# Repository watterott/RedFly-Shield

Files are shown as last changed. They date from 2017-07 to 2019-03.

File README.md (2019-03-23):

# RedFly-Shield
The RedFly-Shield is a plug-on module with WiFi/WLAN for Arduino.

Alternative: [BlueFly-Shield](https://github.com/watterott/BlueFly-Shield) with Atmel/Microchip ATWINC1500-MR210PB WiFi module.

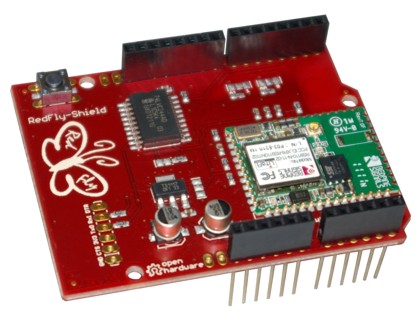
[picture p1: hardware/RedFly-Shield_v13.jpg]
RedFly-Shield


* [Redpine Signals RS9110-N-11-22](http://www.redpinesignals.com/Modules/Internet_of_Things/Connection_Family/RS-9110-N-11-22.php) WiFi module
* Compliant to 802.11b/g and single stream 802.11n
* Network standard: IEEE 802.11b/g/n 2.4GHz
* Wireless security: AES, WEP, WPA, WPA2
* Modes: Ad-hoc (only WEP encryption) and Infrastructure (no Access-Point mode)
* Scanning for networks with signal strength indicator
* Integrated WiFi and IPv4 stack (TCP, UDP, ARP, ICMP, DHCP, Auto-IP, DNS)
* Supports up to 7 sockets at the same time
* On-board Antenna
* 3.3V - 5V tolerant IOs
* Open-Source and released under the [Creative Commons Attribution Share-Alike License](https://creativecommons.org/licenses/by-sa/4.0/).

## Hardware and Software
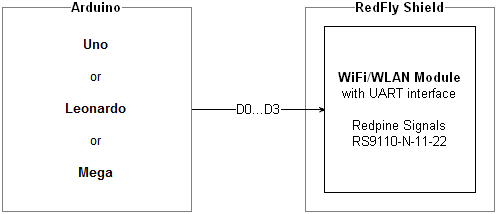
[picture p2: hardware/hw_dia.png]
RedFly-Shield hardware dia
* 
* [Schematics + Layout](https://github.com/watterott/RedFly-Shield/tree/master/hardware)
* [Arduino Library and Examples](https://github.com/watterott/Arduino-Libs)
* [DHCP + DNS servers](https://github.com/pkulchenko/DHCPLite/)

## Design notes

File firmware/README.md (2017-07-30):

Firmware Update Guide: https://github.com/watterott/RedFly-Shield/tree/master/firmware/update_guide

## Release notes

* 4.7.1
  * Wireless firmware upgrade and configuration feature.
  * Added support for 4 WEP keys.
  * Fixed TCP max payload length 1460 and UDP max payload length 1472.
  * Uses the new RF and BB programming values to improve sensitivity.
  * Improve the accuracy of RSSI value by doing averaging.
  * Support for 32 byte SSID.
  * Number of sockets supported limited to 7.

* 4.5.0
  * Fixed some IBSS issues.
  * Fix for not sending ack for reset from remote peer.
  * WPA/WPA2 password with up to 63 characters.

* 4.4.6
  * Fixed IBSS issues in high traffic scenarios.
  * Added TCP keep alive functionality.
  * Added retry mechanism for TCP SYN-ACK packet.

* 4.4.5
  * Fixed issue with TCP server in handling more than one socket with the same port nnumber.
  * Bugfix in WEP security mode.

* 4.3.0
  * Supporting DNS client.
  * Supporting Multicast socket.
  * Supporting Auto IP.
  * Supporting WEP security mode in IBSS network.

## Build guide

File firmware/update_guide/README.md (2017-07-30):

# How to update the RedFly Firmware?

## Update under Windows with Hyper Terminal

* Load the **FWupdate** Sketch into the Arduino Board.

* Connect a 3V3 FTDI Basic-Breakout to the FTDI-3V3 connector on the RedFly.<br>
  Or you can also use an **Arduino with FTDI chipset** for the update
  (baud rate error on the boards with ATmega8u2/16u2 is too high, e.g. UNO, MEGA 2560).
  In this case connect pin 0 to FTDI-3V3 pin 4 (TxO) and pin 1 to FTDI-3V3 pin 5 (RxI):<br>
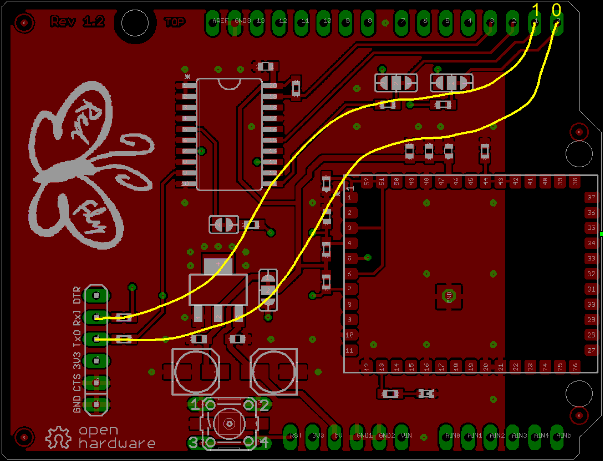
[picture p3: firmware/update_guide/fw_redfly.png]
RedFly-Shield
  

* Run Windows Hyper Terminal: **115200 baud, 8N1, no handshake**<br>
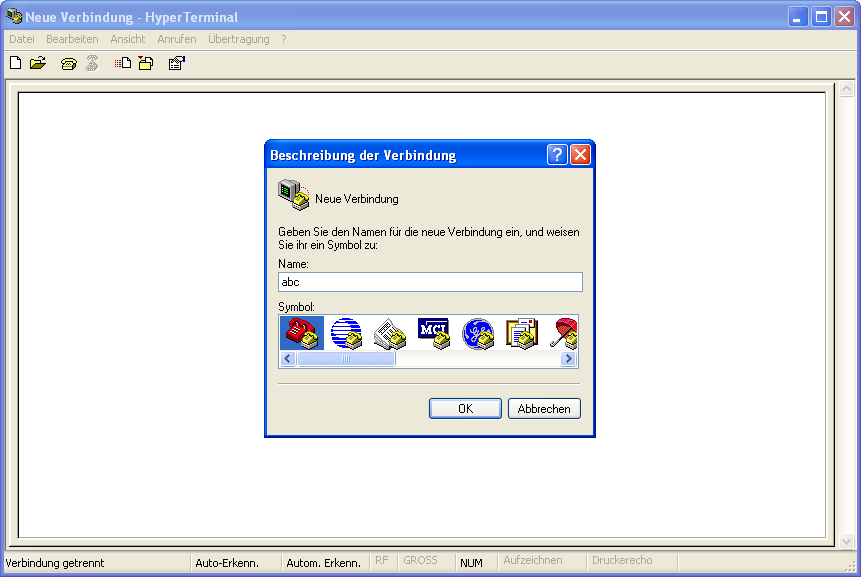
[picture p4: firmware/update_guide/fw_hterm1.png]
HTerm
  
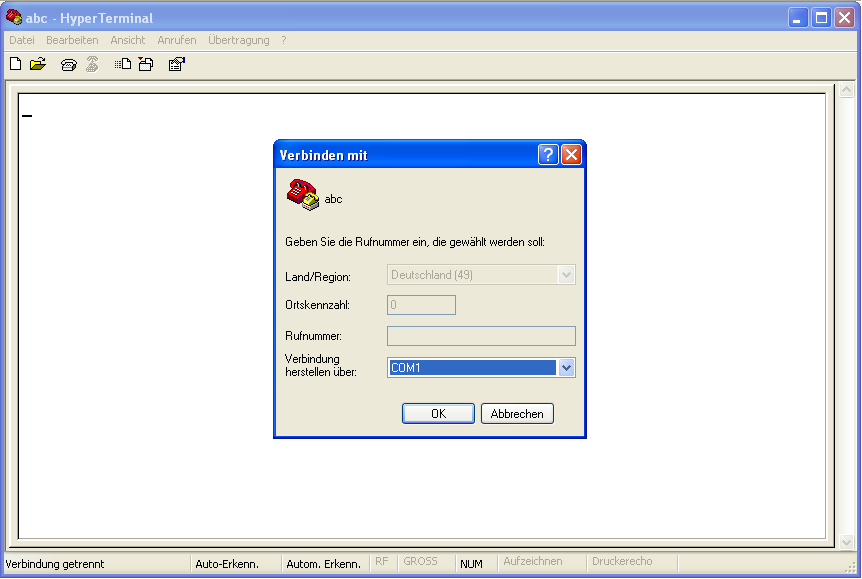
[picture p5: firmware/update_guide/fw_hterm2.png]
HTerm
  
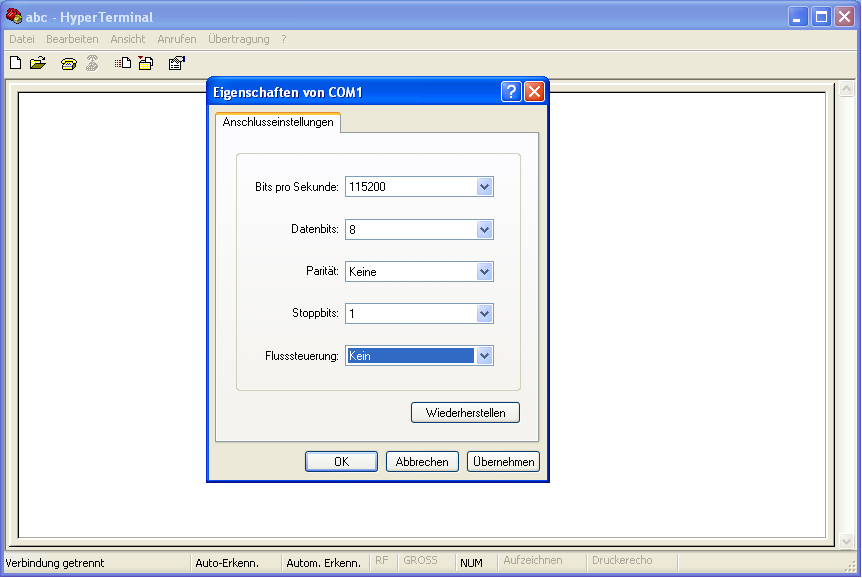
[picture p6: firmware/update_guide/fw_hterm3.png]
HTerm
  

* Power cycle the Arduino+RedFly and make sure that on the RedFly no LED is on. If a LED is on then power cycle again.

* Start connection on the serial port and wait about 20 seconds. Then the module starts with the default settings.

* On the firmware upgrade question press **y**.

        WELCOME TO REDPINE SIGNALS
        Firmware upgrade (y/n) y

* Send the respected file when the prompt Send xxx appears and use the Kermit protocol.

        WELCOME TO REDPINE SIGNALS
        Firmware upgrade (y/n) y
        Send taim1,taim2,tadm1,tadm2 files in order to upgrade the firmware
        Send taim1

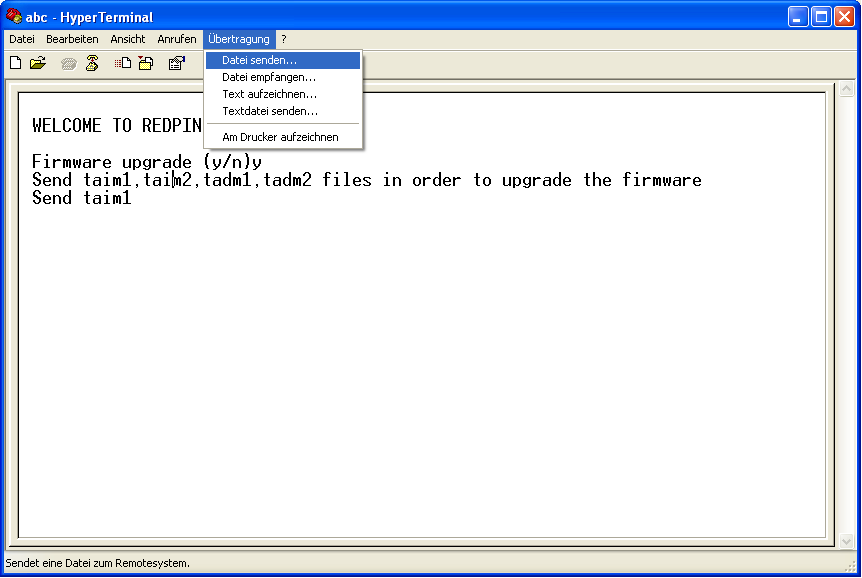
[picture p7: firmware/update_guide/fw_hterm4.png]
HTerm
  
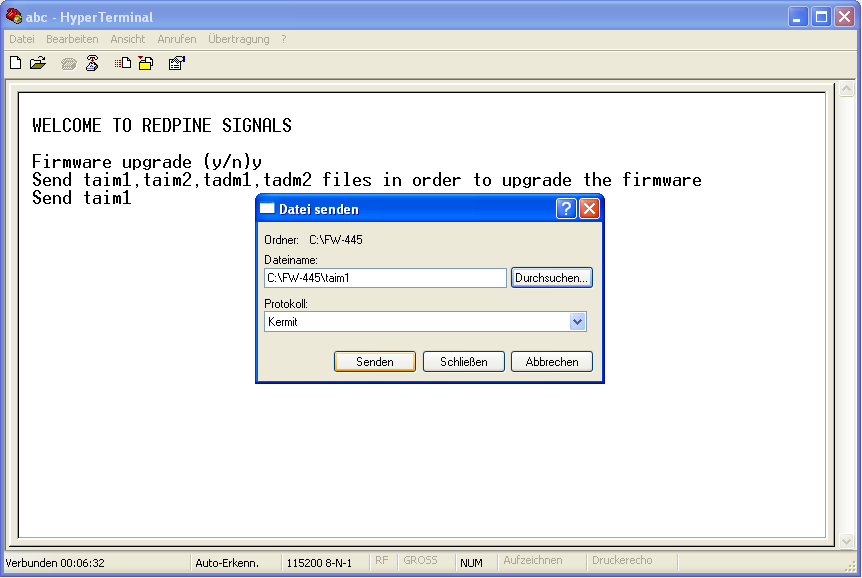
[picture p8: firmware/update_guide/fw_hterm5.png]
HTerm
  
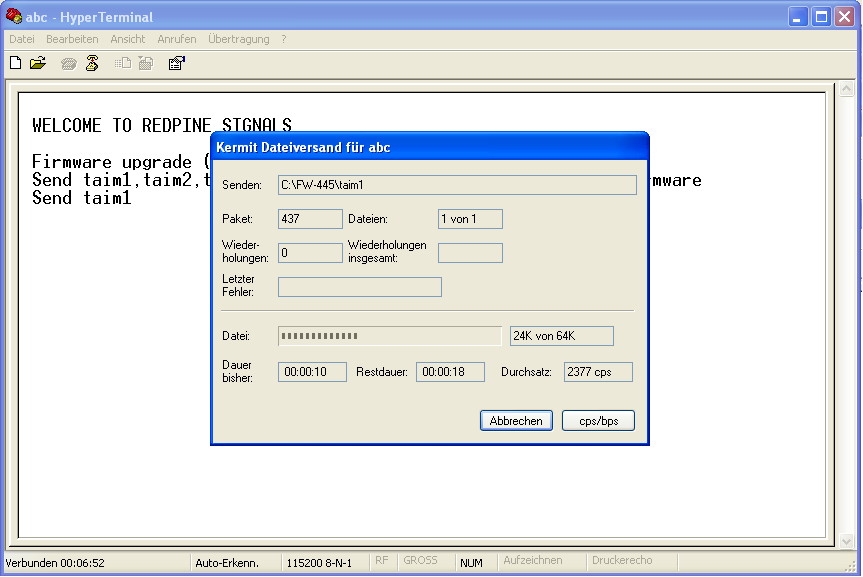
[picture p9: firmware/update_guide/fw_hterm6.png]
HTerm
  

* Power cycle the Arduino+RedFly after the update is completed.

        WELCOME TO REDPINE SIGNALS
        Firmware upgrade (y/n) y
        Send taim1,taim2,tadm1,tadm2 files in order to upgrade the firmware
        Send taim1
        Send taim2
        Send tadm1
        Send tadm2
        Firmware Upgradation completed

## Update under Linux with kermit

Alternatively it's also possible to do the firmware update with kermit.

* Run kermit with the following settings and start the serial console.

        $ sudo kermit
        
        set xm li on
        set line /dev/ttyUSB0
        set speed 115200
        set modem type none
        set flow-control none
        set handshake none
        connect

* On the firmware upgrade question press **y**.

        WELCOME TO REDPINE SIGNALS
        Firmware upgrade (y/n) y
        Send taim1,taim2,tadm1,tadm2 files in order to upgrade the firmware
        Send taim1

* Go back ```CTRL+\, C``` and send the first file.

        send taim1

* Go to the serial console (type ```connect```).

        connect

* Wait for ```Send taim2```, then go back, send the file and return to the serial console.

* Wait for ```Send tadm1```, then go back, send the file and return to the serial console.

* Wait for ```Send tadm2```, then go back, send the file and return to the serial console.

* Wait for ```Firmware Upgradation completed```.

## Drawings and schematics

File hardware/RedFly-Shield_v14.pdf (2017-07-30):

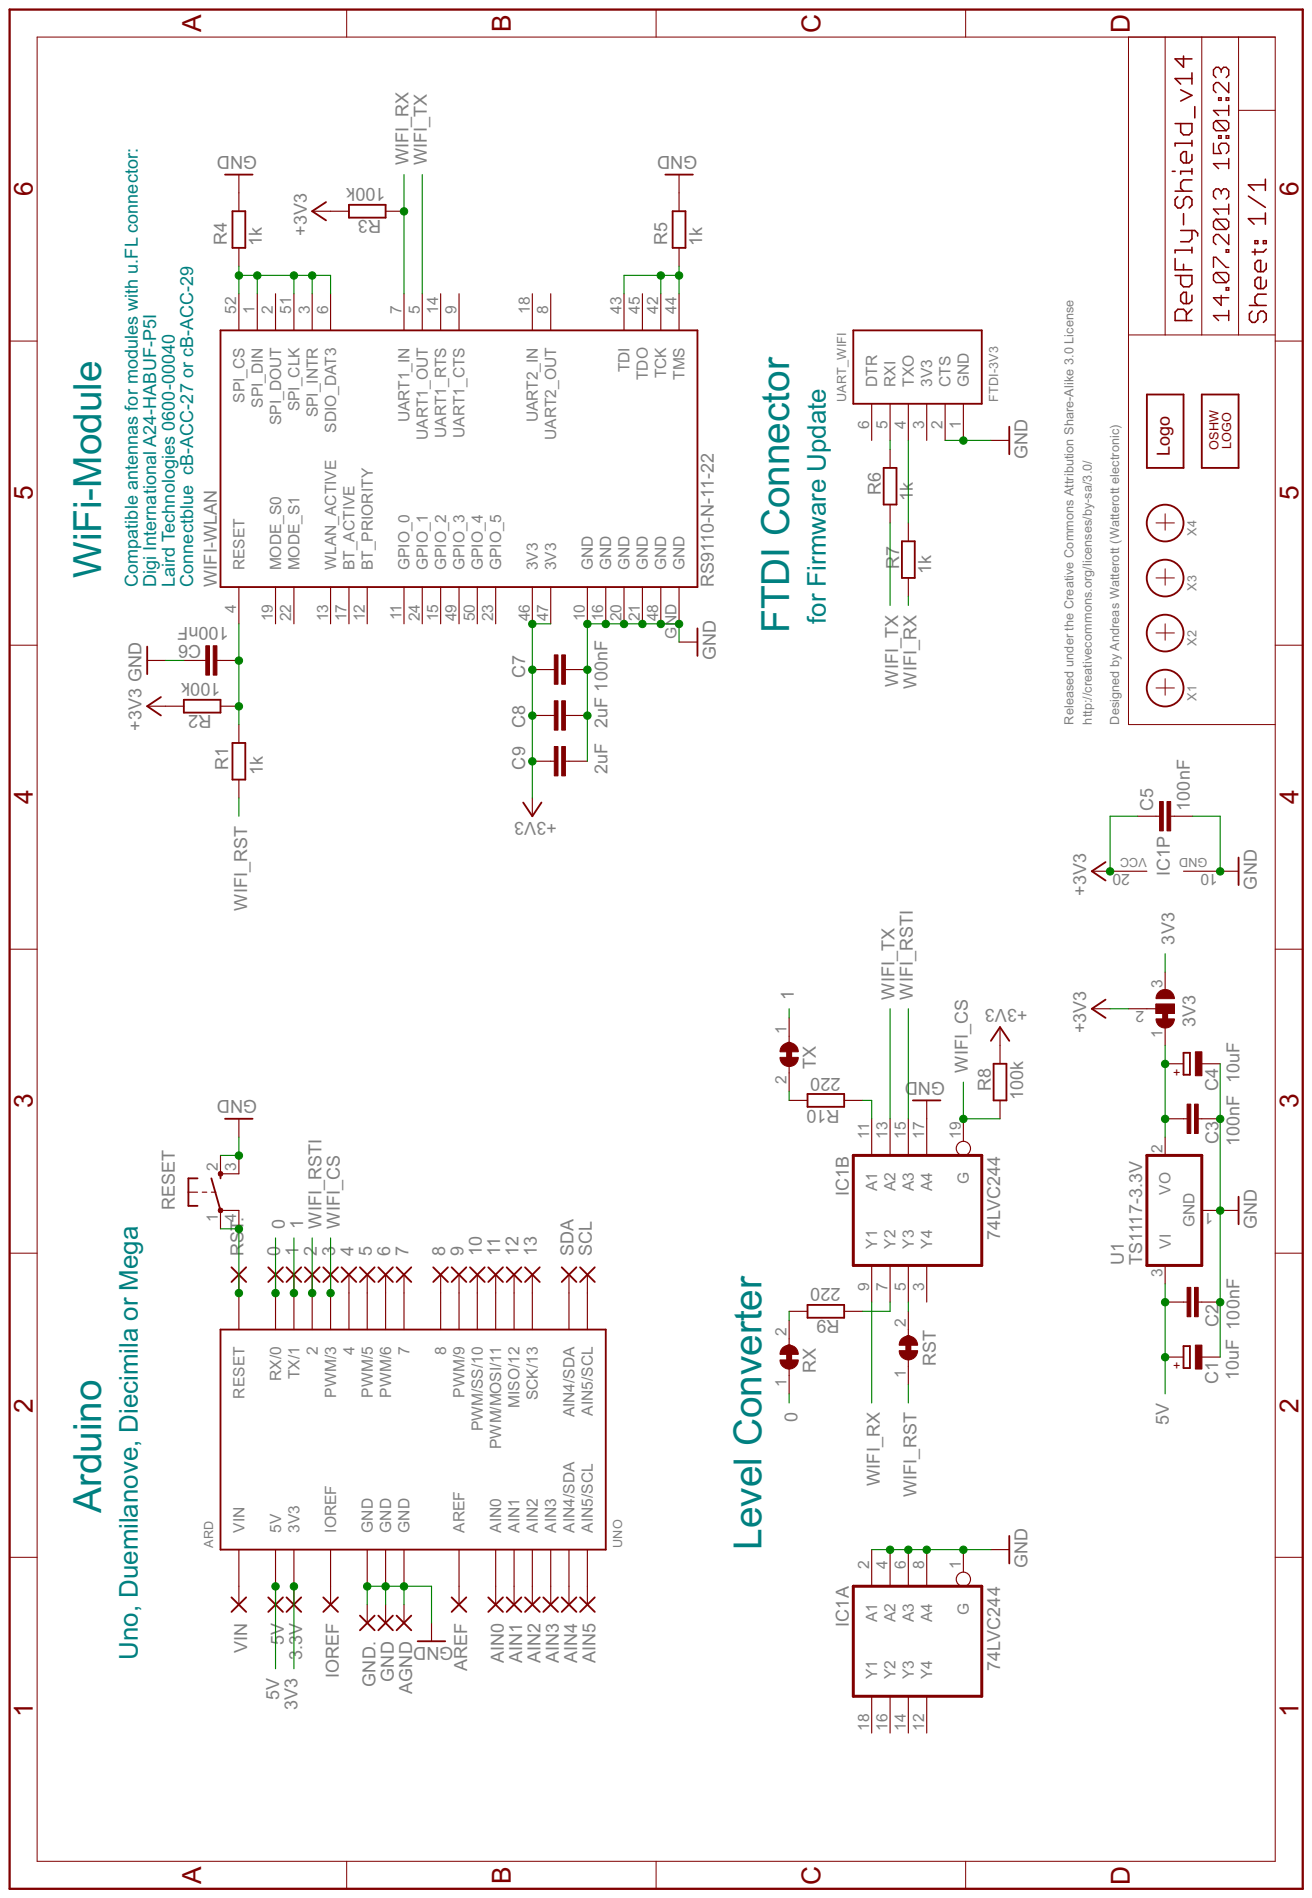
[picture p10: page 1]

Compatible antennas for modules with u.FL connector: Digi International A24-HABUF-P5I Laird Technologies 0600-00040 Connectblue cB-A

Released under the Creative Commons Attribution Share-Alike 3.0 License

http://creativecommons.org/licenses/by-sa/3.0/ Designed by Andreas Watterott (Watterott electronic)

8 PWM/9 PWM/SS/10 PWM/MOSI/11 MISO/12 SCK/13 AIN1 AIN2 AIN3 AIN4/SDA

IOREF GND GND GND

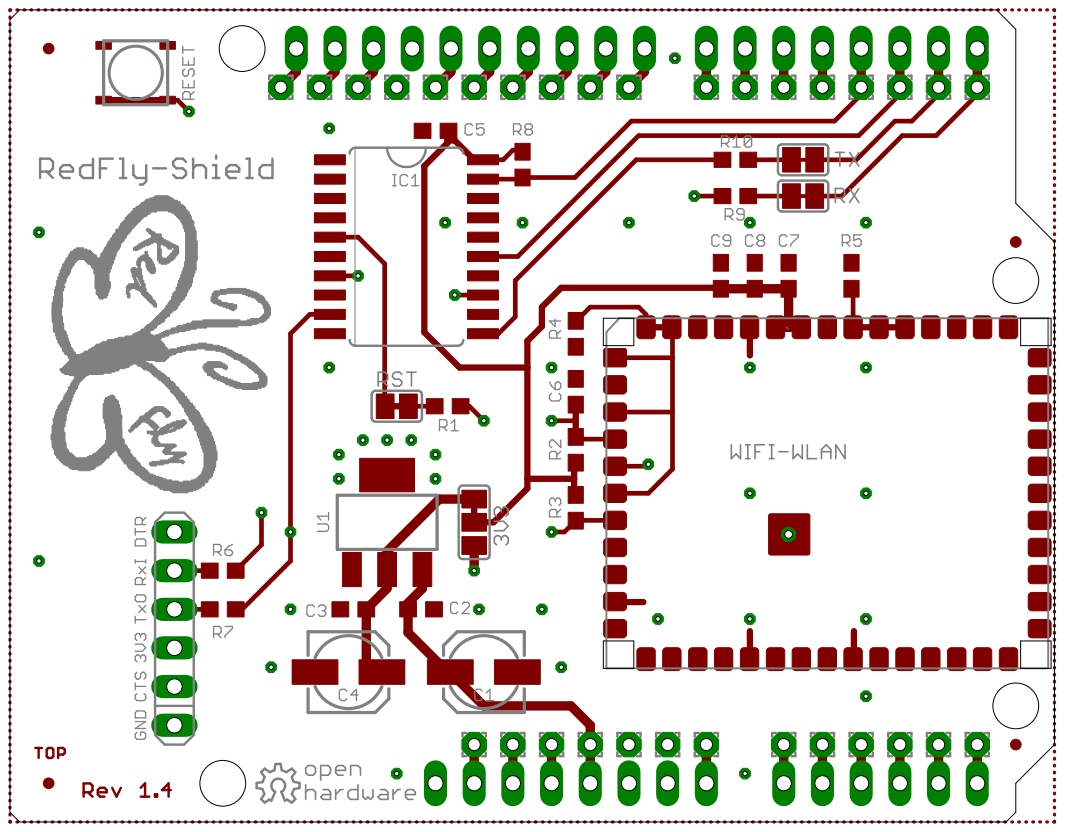
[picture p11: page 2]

# Antenna Options

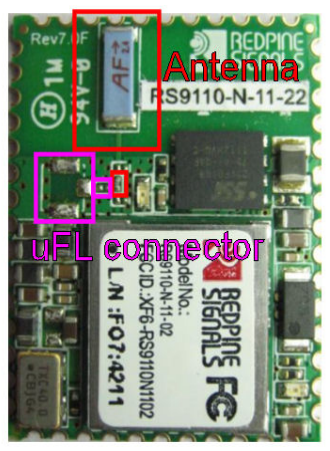
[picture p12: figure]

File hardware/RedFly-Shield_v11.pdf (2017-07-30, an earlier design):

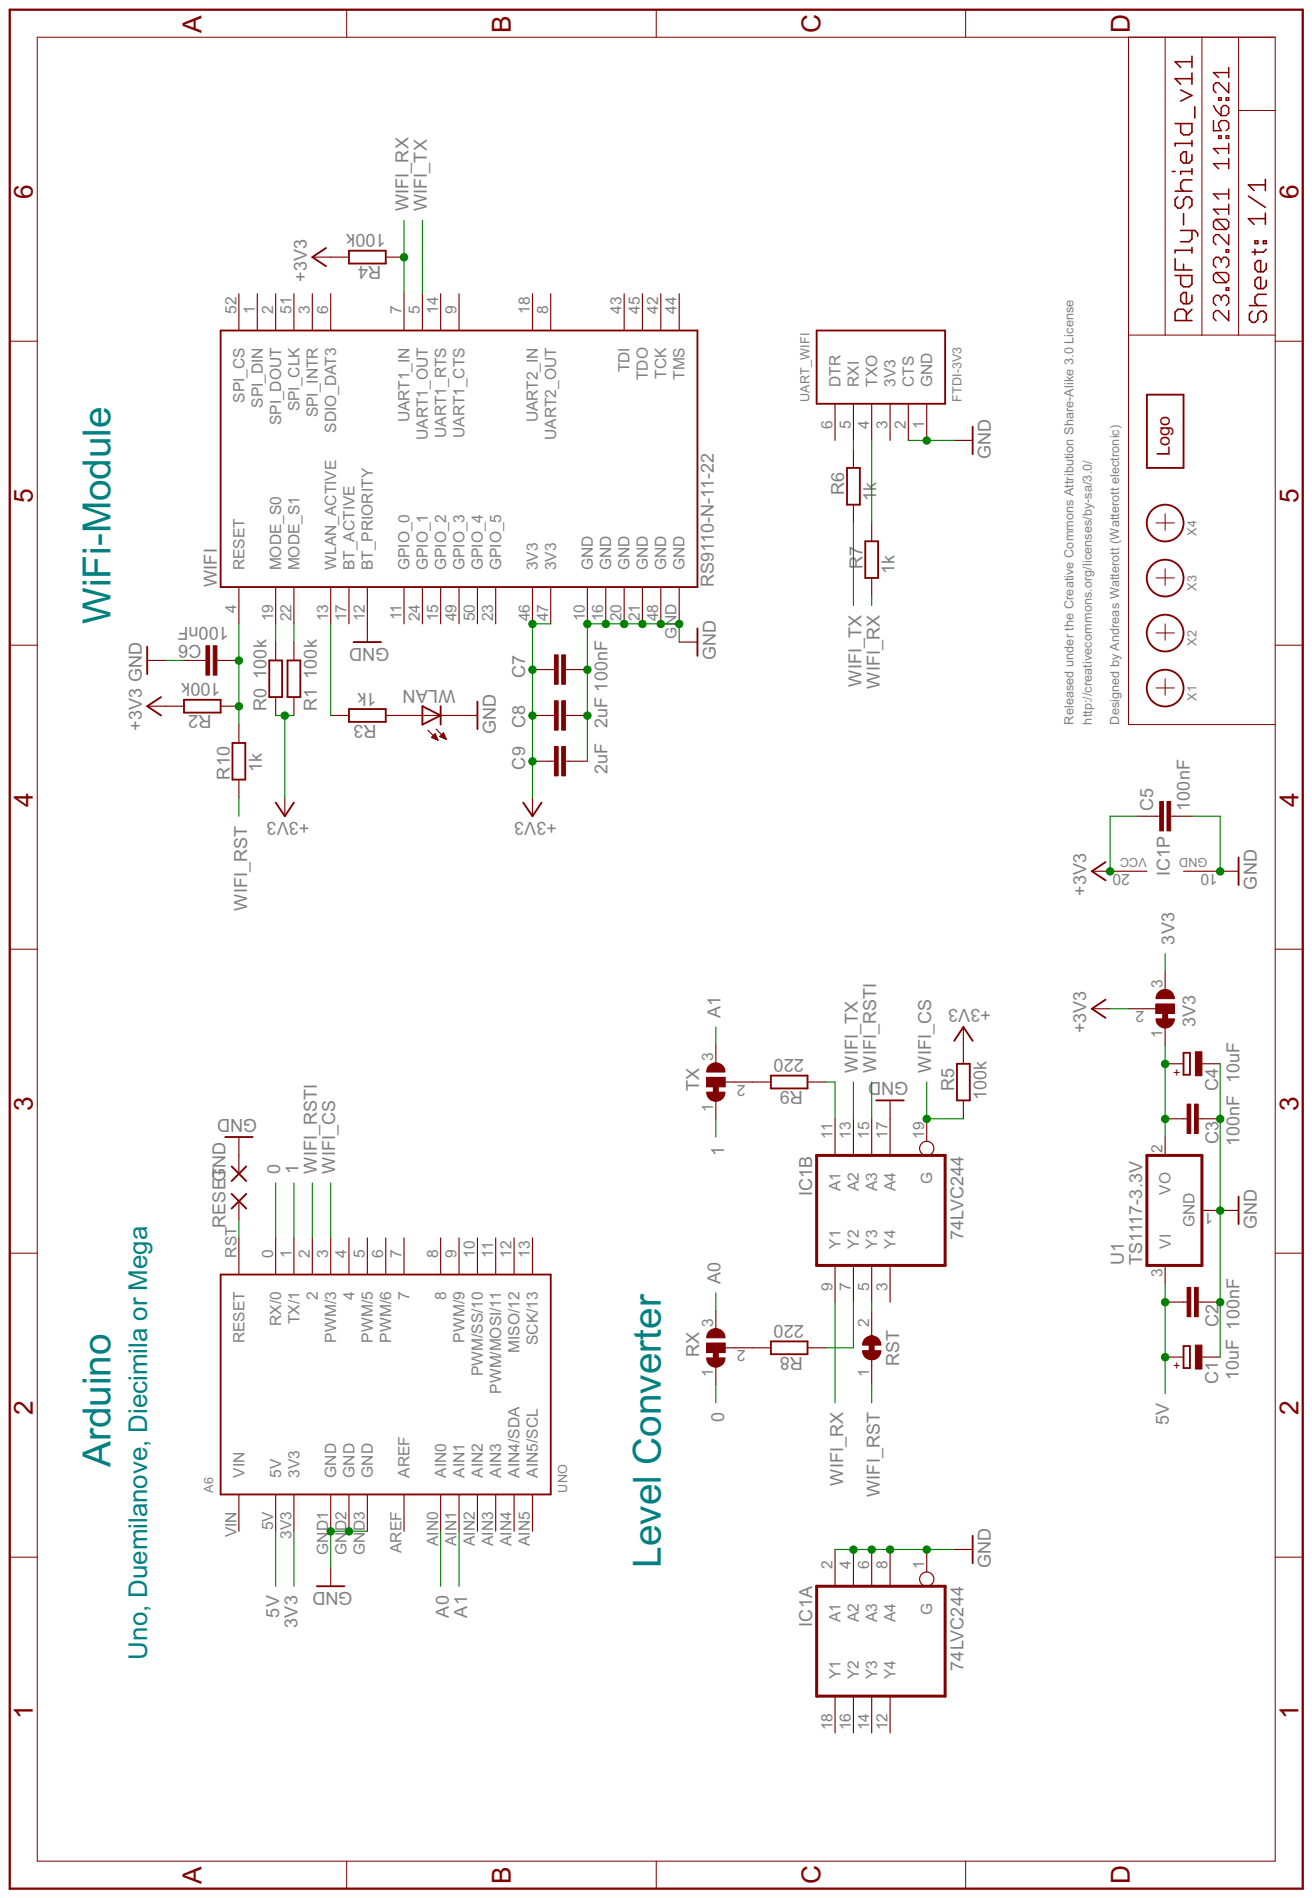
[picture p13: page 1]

GND 100nF 2uF 74LVC244 74LVC244 GND +3V3 100nF GND DNG +3V3 DNG DNG 3V3+ GND k001 +3V3 DNG GNDk1 Fn001 GND TS1117-3.3V 100nF 100n 1F 00k 3V3+ k001 +3V3 1k 1k GND 100k 100k 3V3+ 2uF 10uF 10uF 022 022 1k Released under the Creative Commons Attribution Share-Alike 3.0 License http://creativecommons.org/licenses/by-sa/3.0/ Designed by Andreas Watterott (Watterott electronic) C7 C8 G 1 A1 2 A2 4 A3 6 A4 8 Y4 12 Y3 14 Y2 16 Y1 18 IC1A G 19 A1 11 A2 13 A3 15 A4 17 Y4 3 Y3 5 Y2 7 Y1 9 IC1B 02 01 CCV DNG IC1P C5 3 1 2 3V3 RESETGND X1 X2 X3 X4 WIFI RS9110-N-11-22 GND 10 GND 16 GND 20 GND 21 GND 48 3V3 46 3V3 47 SPI_DIN 1 SPI_DOUT 2 SPI_INTR 3 RESET 4 UART1_OUT 5 SDIO_DAT3 6 UART1_IN 7 UART2_OUT 8 UART1_CTS 9 GPIO_0 11 BT_PRIORITY 12 WLAN_ACTIVE 13 UART1_RTS 14 GPIO_2 15 BT_ACTIVE 17 UART2_IN 18 MODE_S0 19 MODE_S1 22 GPIO_5 23 GPIO_1 24 GPIO_3 49 GPIO_4 50 TDI 43 TDO 45 TCK 42 TMS 44 SPI_CLK 51 SPI_CS 52 GND GND A6UNO RX/0 0 TX/1 1 2 2 AIN0 AIN0 PWM/3 3 4 4 PWM/5 5 PWM/6 6 7 7 8 8 PWM/9 9 PWM/SS/10 10 PWM/MOSI/11 11 MISO/12 12 SCK/13 13 AIN1 AIN1 AIN2 AIN2 AIN3 AIN3 AIN4/SDA AIN4 AIN5/SCL AIN5 5V 5V GND GND1 GND GND2 VIN VIN 3V3 3V3 GND GND3 AREF AREF RESET RST 2R NAL W 3R 6C VI 3 1 VO 2 U1 GND C2 C3 R5 4R UART_WIFI FTDI-3V3 DTR 6 RXI 5 TXO 4 3V3 3 CTS 2 GND 1 R6 R7 R1R0 C9 C4 C1 8R9R 3 1 2 TX 3 1 2 RX 2 1RST R10 5V 5V 3V3 3V3 WIFI_RX WIFI_RX WIFI_RX WIFI_TX WIFI_TX WIFI_TX 0 0 1 1 WIFI_CS WIFI_CS A0 A0 A1 A1 WIFI_RSTI WIFI_RSTI WIFI_RST WIFI_RST ABCD 1 2 3 4 5 6 ABCD 1 2 3 4 5 6 Logo ++ Arduino Level Converter WiFi-Module Uno, Duemilanove, Diecimila or Mega

# Antenna Options


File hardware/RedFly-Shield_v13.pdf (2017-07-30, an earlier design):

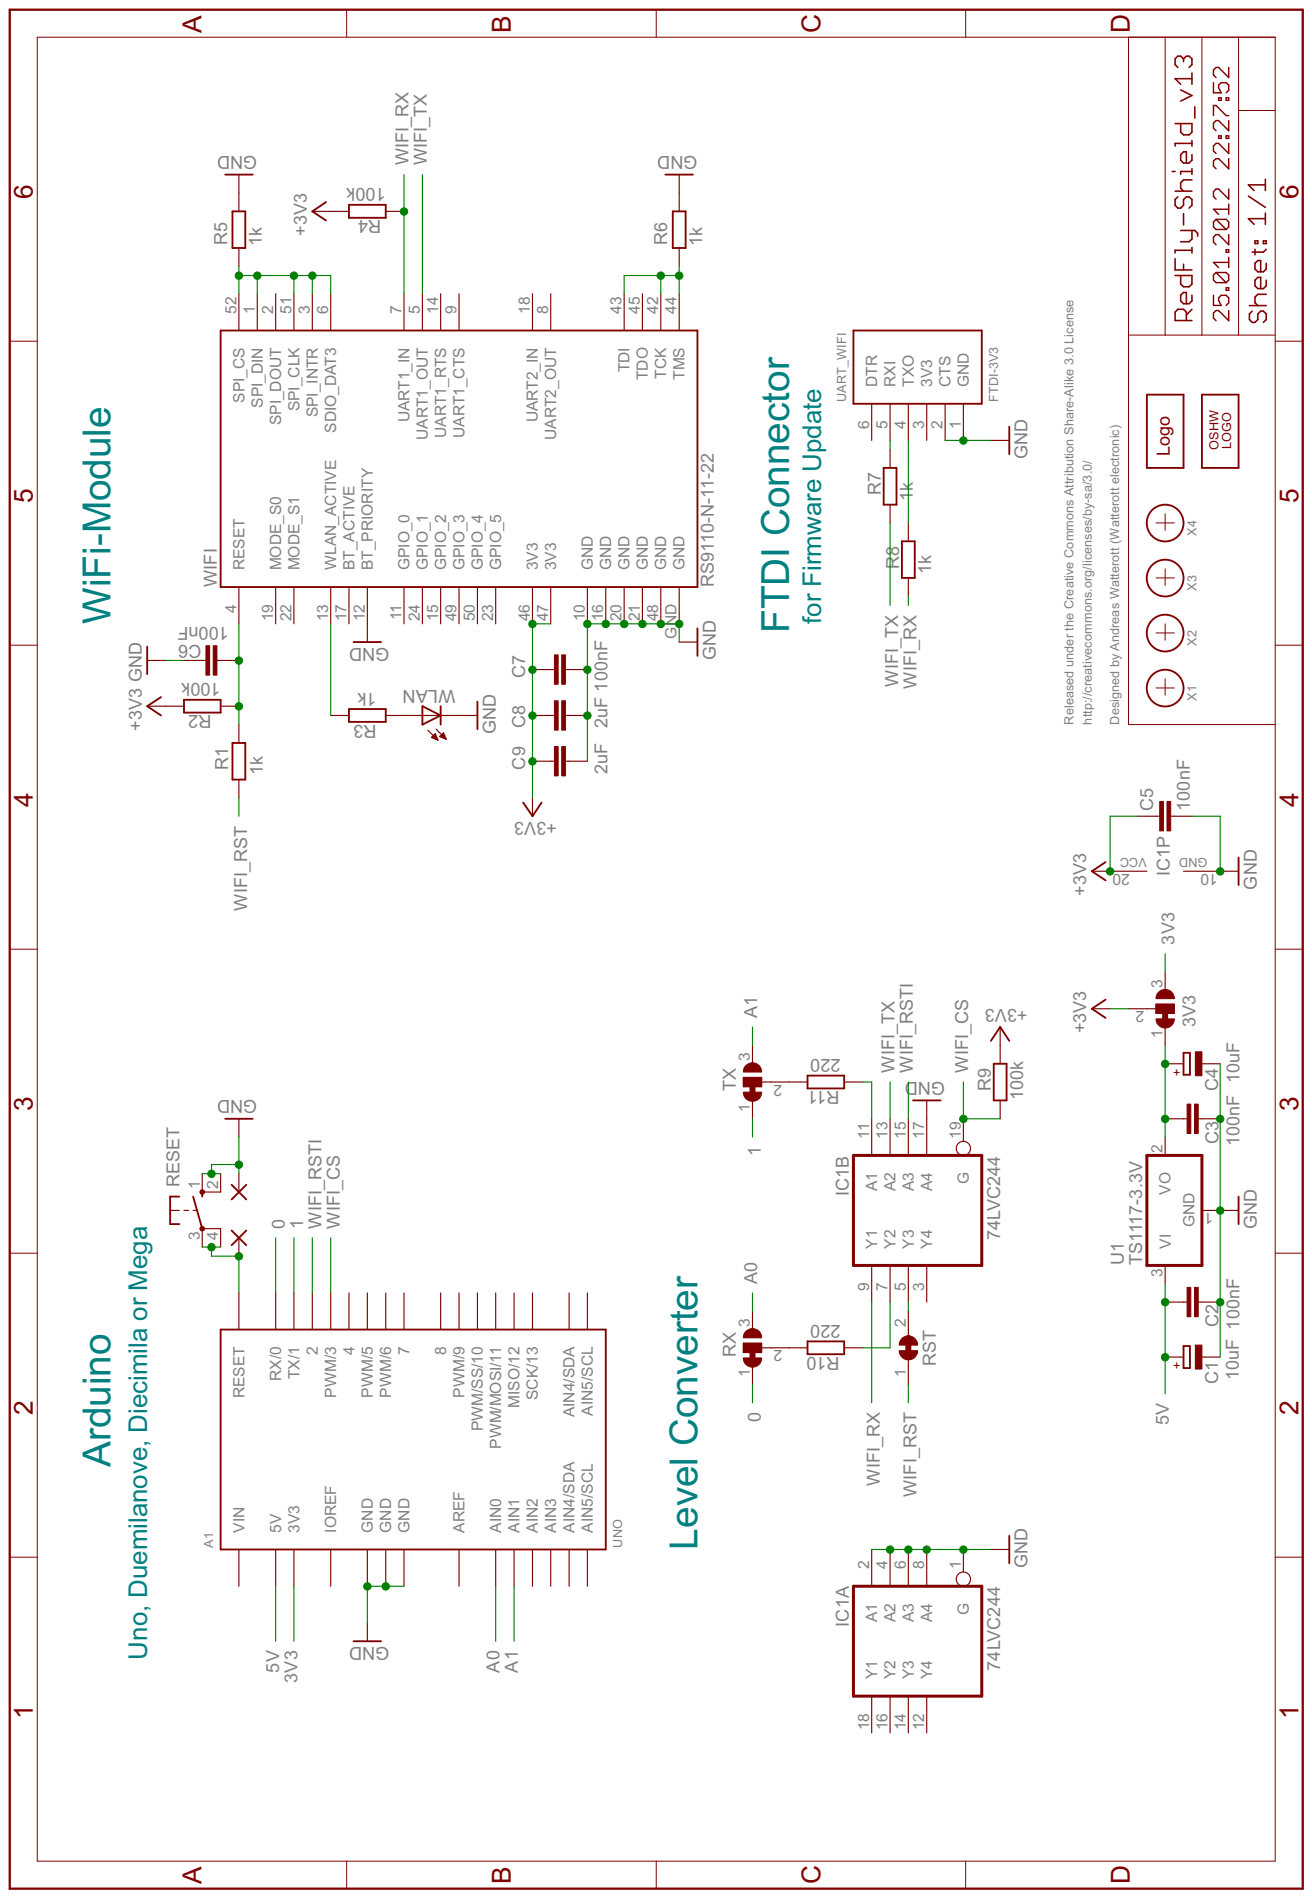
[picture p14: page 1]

Released under the Creative Commons Attribution Share-Alike 3.0 License

http://creativecommons.org/licenses/by-sa/3.0/ Designed by Andreas Watterott (Watterott electronic)

8 PWM/9 PWM/SS/10 PWM/MOSI/11 MISO/12 SCK/13 AIN1 AIN2 AIN3 AIN4/SDA

IOREF GND GND GND

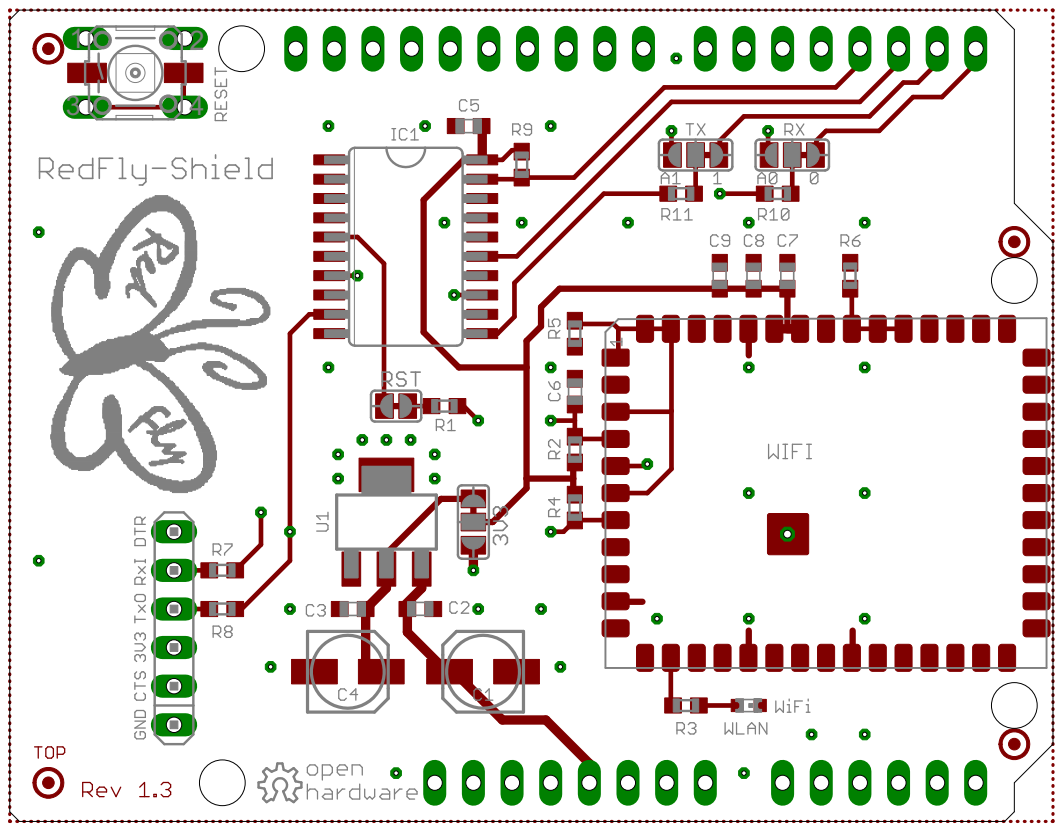
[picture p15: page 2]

# Antenna Options


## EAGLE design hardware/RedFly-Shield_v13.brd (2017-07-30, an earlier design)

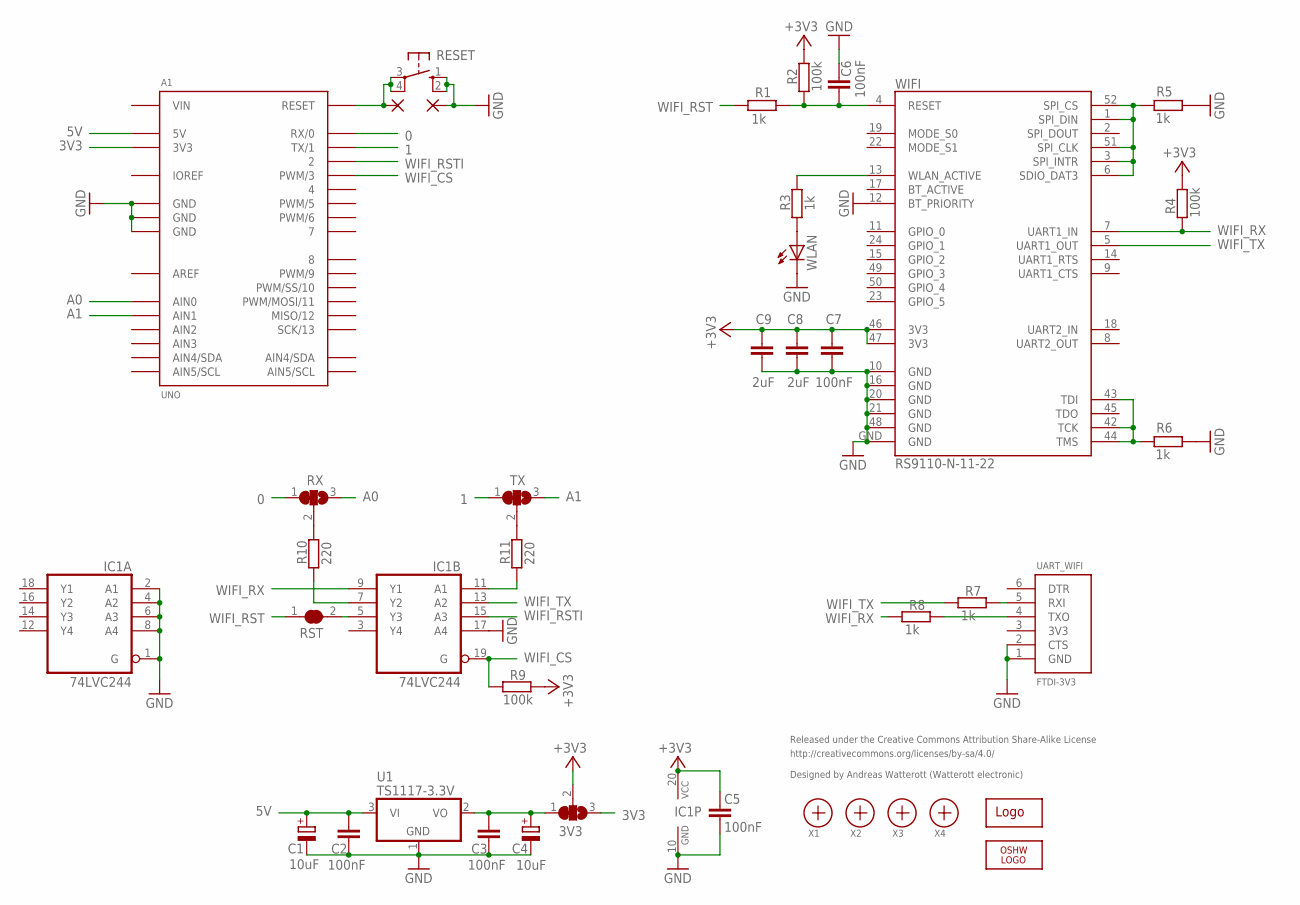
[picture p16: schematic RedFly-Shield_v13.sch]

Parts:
3V3: SJ2W; SJ_2
A1: UNO
C1, C4: 10uF; 153CLV-0505
C2, C3, C5, C6, C7: 100nF; C0603
C8, C9: 2uF; C0603
GND: SMD2; SMD1,27-2,54
IC1: 74LVC244; SO20W
LOGO1: OSHW_LOGO_6MILX0100-NT; OSHW_6X100_NOTEXT
R1, R3, R5, R6, R7, R8: 1k; R0603
R2, R4, R9: 100k; R0603
R10, R11: 220; R0603
RESET: 10-XX; B3F-10XX
RST: SJ
RST2: SMD2; SMD1,27-2,54
RX: SJ2W; SJ_2
TX: SJ2W; SJ_2
U1: TS1117-3.3V; SOT223
U$1: WE-LOGO
UART_WIFI: FTDI-3V3; FTDI
WIFI: RS9110-N-11-22; RS9110-N-11-21
WLAN: LEDCHIPLED_0603; CHIPLED_0603
X1, X2, X3, X4: PASSER

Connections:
0: A1.0 (RX/0), RX.1
1: A1.1 (TX/1), TX.1
3V3: 3V3.3, A1.3V3
3V_OUT: 3V3.1, C3.1, C4.+, U1.2 (VO)
5V: A1.5V, C1.+, C2.1, U1.3 (VI)
+3V3: 3V3.2, C5.1, C7.1, C8.1, C9.1, IC1.20 (VCC), R2.2, R4.1, R9.2, WIFI.46 (3V3), WIFI.47 (3V3)
A0: A1.AIN0, RX.3
A1: A1.AIN1, TX.3
AREF: A1.AREF
GND: A1.GND@1 (GND), A1.GND@2 (GND), A1.GND@3 (GND), C1.-, C2.2, C3.2, C4.-, C5.2, C6.1, C7.2, C8.2, C9.2, GND.1, IC1.1 (G), IC1.2 (A1), IC1.4 (A2), IC1.6 (A3), IC1.8 (A4), IC1.10 (GND), IC1.17 (A4), R5.1, R6.1, RESET.1 (S), RESET.2 (S1), U1.1 (GND), UART_WIFI.1 (GND), UART_WIFI.2 (CTS), WIFI.10 (GND), WIFI.12 (BT_PRIORITY), WIFI.16 (GND), WIFI.20 (GND), WIFI.21 (GND), WIFI.48 (GND), WIFI.GND, WLAN.C
IOREF: A1.IOREF
unnamed: R6.2, WIFI.42 (TCK), WIFI.43 (TDI), WIFI.44 (TMS)
unnamed: R5.2, WIFI.1 (SPI_DIN), WIFI.3 (SPI_INTR), WIFI.6 (SDIO_DAT3), WIFI.51 (SPI_CLK), WIFI.52 (SPI_CS)
unnamed: R3.1, WIFI.13 (WLAN_ACTIVE)
unnamed: R3.2, WLAN.A
unnamed: R7.1, UART_WIFI.5 (RXI)
unnamed: R8.1, UART_WIFI.4 (TXO)
RST: A1.RST (RESET), RESET.3, RESET.4 (P1), RST2.1
VIN: A1.VIN
WIFI_CS: A1.3 (PWM/3), IC1.19 (G), R9.1
WIFI_RST: R1.2, RST.1
WIFI_RST2: C6.2, R1.1, R2.1, WIFI.4 (RESET)
WIFI_RSTI: A1.2, IC1.15 (A3)
WIFI_RSTO: IC1.5 (Y3), RST.2
WIFI_RX: IC1.9 (Y1), R4.2, R8.2, WIFI.7 (UART1_IN)
WIFI_RX2: R11.1, TX.2
WIFI_RXI: IC1.11 (A1), R11.2
WIFI_TX: IC1.13 (A2), R7.2, WIFI.5 (UART1_OUT)
WIFI_TX2: R10.2, RX.2
WIFI_TXO: IC1.7 (Y2), R10.1

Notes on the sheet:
Released under the Creative Commons Attribution Share-Alike License
http://creativecommons.org/licenses/by-sa/4.0/
Designed by Andreas Watterott (Watterott electronic)

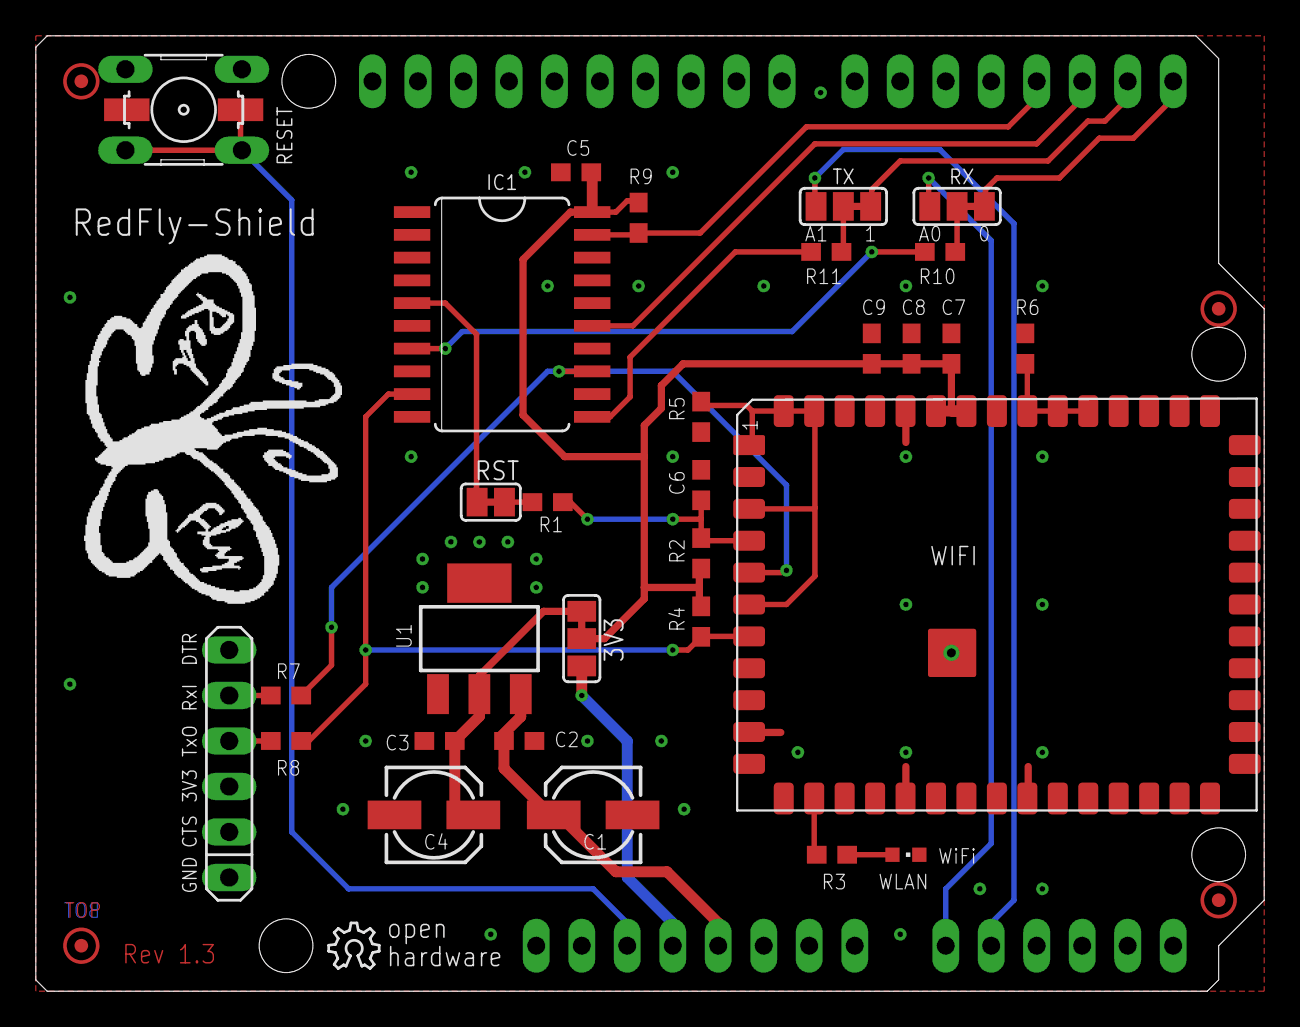
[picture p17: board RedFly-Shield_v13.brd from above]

Board: 2 copper layers, 68.6 x 53.3 mm, 39 parts (1 on the bottom side), 27 nets.

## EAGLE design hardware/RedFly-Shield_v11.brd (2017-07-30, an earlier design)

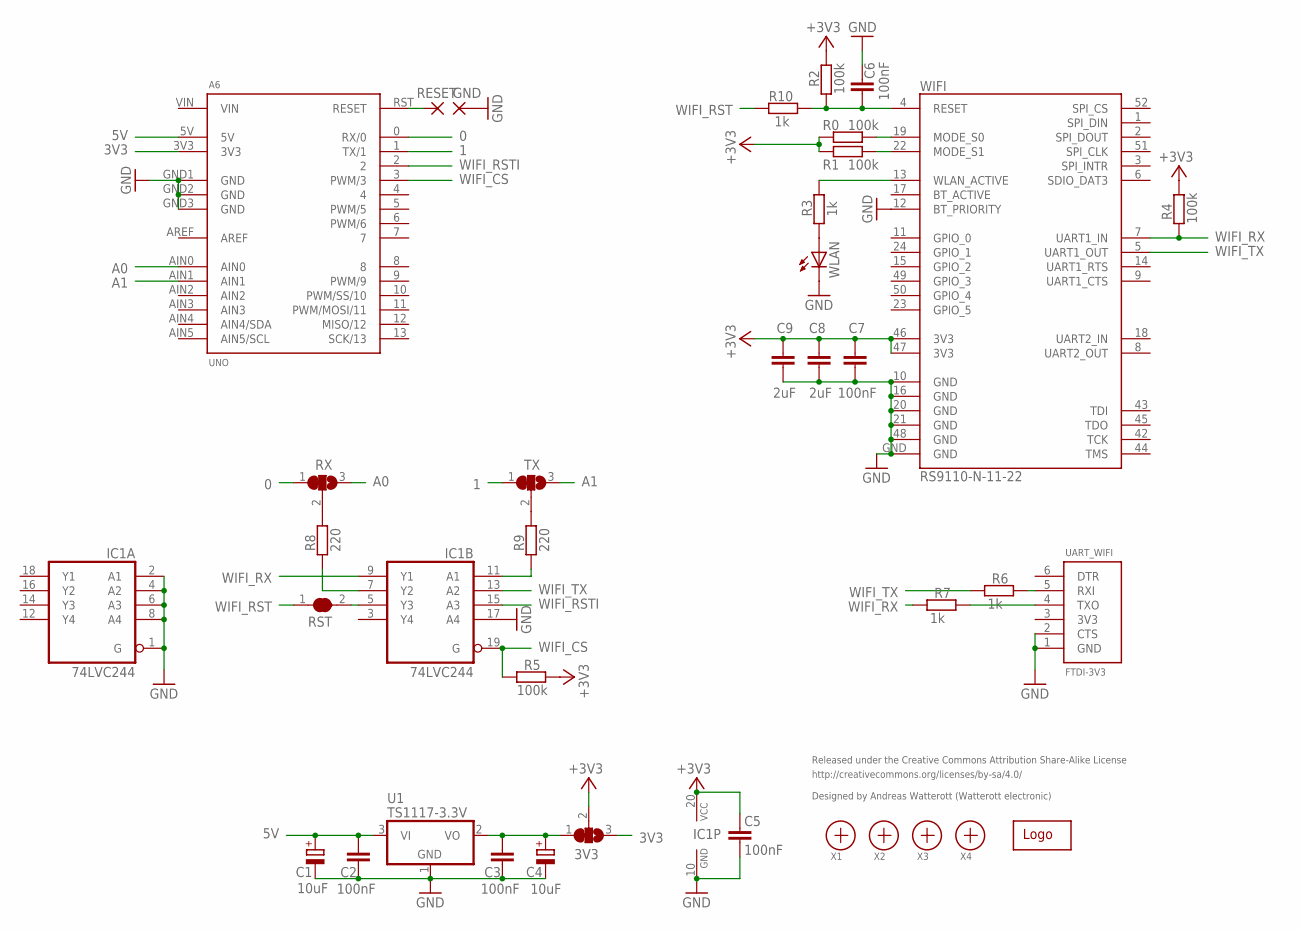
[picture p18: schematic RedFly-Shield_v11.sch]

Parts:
3V3: SJ2W; SJ_2
A6: UNO; DUEMILANOVE
C1, C4: 10uF; 153CLV-0505
C2, C3, C5, C6, C7: 100nF; C0603
C8, C9: 2uF; C0603
GND: SMD2; SMD1,27-2,54
IC1: 74LVC244; SO20W
R0, R1, R2, R4, R5: 100k; R0603
R3, R6, R7, R10: 1k; R0603
R8, R9: 220; R0603
RESET: SMD2; SMD1,27-2,54
RST: SJ
RX: SJ2W; SJ_2
TX: SJ2W; SJ_2
U1: TS1117-3.3V; SOT223
U$1: WE-LOGO
UART_WIFI: FTDI-3V3; FTDI
WIFI: RS9110-N-11-22; RS9110-N-11-21
WLAN: LEDCHIPLED_0805; CHIPLED_0805
X1, X2, X3, X4: PASSER

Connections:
0: A6.0 (RX/0), RX.1
1: A6.1 (TX/1), TX.1
3V3: 3V3.3, A6.3V3
3V_OUT: 3V3.1, C3.1, C4.+, U1.2 (VO)
5V: A6.5V, C1.+, C2.1, U1.3 (VI)
+3V3: 3V3.2, C5.1, C7.1, C8.1, C9.1, IC1.20 (VCC), R0.2, R1.2, R2.2, R4.1, R5.2, WIFI.46 (3V3), WIFI.47 (3V3)
A0: A6.AIN0, RX.3
A1: A6.AIN1, TX.3
AREF: A6.AREF
GND: A6.GND1 (GND), A6.GND2 (GND), A6.GND3 (GND), C1.-, C2.2, C3.2, C4.-, C5.2, C6.1, C7.2, C8.2, C9.2, GND.1, IC1.1 (G), IC1.2 (A1), IC1.4 (A2), IC1.6 (A3), IC1.8 (A4), IC1.10 (GND), IC1.17 (A4), U1.1 (GND), UART_WIFI.1 (GND), UART_WIFI.2 (CTS), WIFI.10 (GND), WIFI.12 (BT_PRIORITY), WIFI.16 (GND), WIFI.20 (GND), WIFI.21 (GND), WIFI.48 (GND), WIFI.GND, WLAN.C
unnamed: R0.1, WIFI.19 (MODE_S0)
unnamed: R1.1, WIFI.22 (MODE_S1)
unnamed: R3.1, WIFI.13 (WLAN_ACTIVE)
unnamed: R3.2, WLAN.A
unnamed: R6.1, UART_WIFI.5 (RXI)
unnamed: R7.1, UART_WIFI.4 (TXO)
RST: A6.RST (RESET), RESET.1
VIN: A6.VIN
WIFI_CS: A6.3 (PWM/3), IC1.19 (G), R5.1
WIFI_RST: R10.2, RST.1
WIFI_RST2: C6.2, R2.1, R10.1, WIFI.4 (RESET)
WIFI_RSTI: A6.2, IC1.15 (A3)
WIFI_RSTO: IC1.5 (Y3), RST.2
WIFI_RX: IC1.9 (Y1), R4.2, R7.2, WIFI.7 (UART1_IN)
WIFI_RX2: R9.1, TX.2
WIFI_RXI: IC1.11 (A1), R9.2
WIFI_TX: IC1.13 (A2), R6.2, WIFI.5 (UART1_OUT)
WIFI_TX2: R8.2, RX.2
WIFI_TXO: IC1.7 (Y2), R8.1

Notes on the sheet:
Released under the Creative Commons Attribution Share-Alike License
http://creativecommons.org/licenses/by-sa/4.0/
Designed by Andreas Watterott (Watterott electronic)

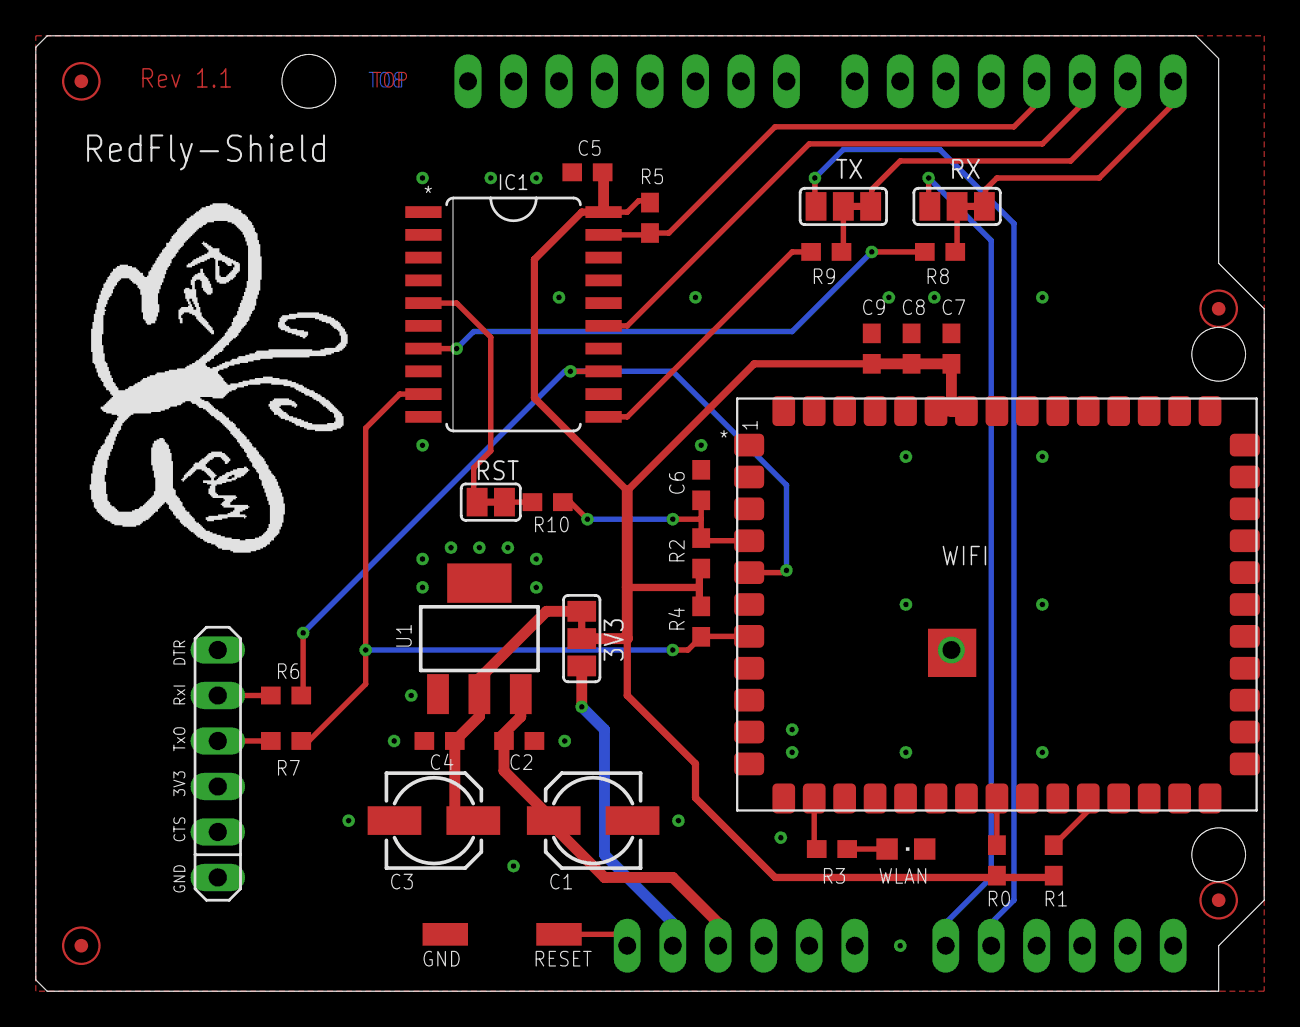
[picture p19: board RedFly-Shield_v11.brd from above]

Board: 2 copper layers, 68.6 x 53.3 mm, 37 parts (1 on the bottom side), 27 nets.

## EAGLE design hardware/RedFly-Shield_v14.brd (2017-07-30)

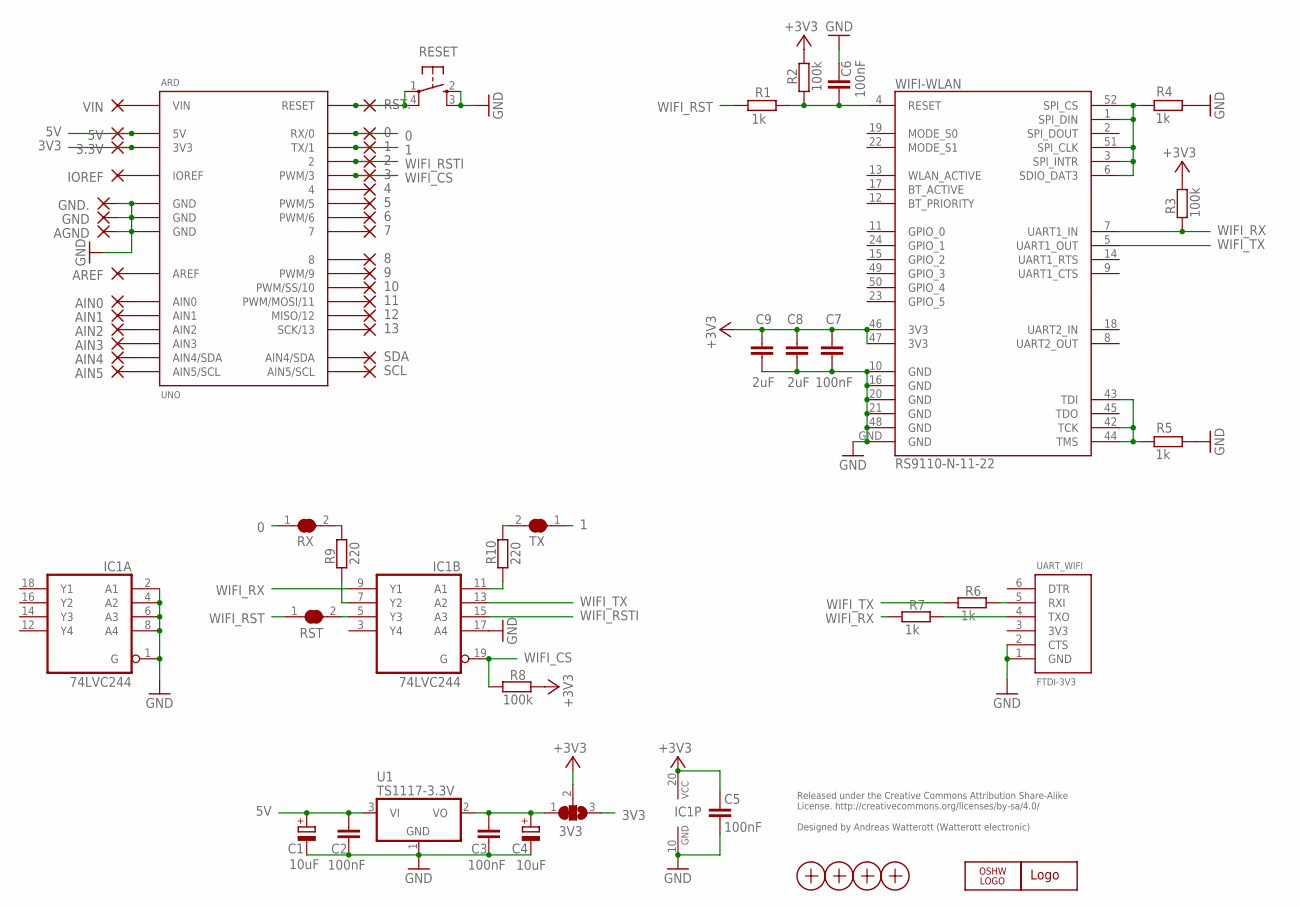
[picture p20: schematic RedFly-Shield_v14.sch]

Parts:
0, 1, 2, 3, 3.3V, 4, 5, 5V, 6, 7, 8, 9, 10, 11, 12, 13: WIREPAD1,6/0,8; 1,6/0,8
3V3: SJ2W; SJ_2
AGND: WIREPAD1,6/0,8; 1,6/0,8
AIN0, AIN1, AIN2, AIN3, AIN4, AIN5: WIREPAD1,6/0,8; 1,6/0,8
ARD: UNO
AREF: WIREPAD1,6/0,8; 1,6/0,8
C1, C4: 10uF; 153CLV-0505
C2, C3, C5, C6, C7: 100nF; C0603
C8, C9: 2uF; C0603
GND, GND.: WIREPAD1,6/0,8; 1,6/0,8
IC1: 74LVC244; SO20W
IOREF: WIREPAD1,6/0,8; 1,6/0,8
LOGO1: WE-LOGO
LOGO2: OSHW_LOGO_6MILX0100-NT; OSHW_6X100_NOTEXT
R1, R4, R5, R6, R7: 1k; R0603
R2, R3, R8: 100k; R0603
R9, R10: 220; R0603
RESET: SW_SMDS; SW_SMD4@1
RST: SJ
RST.: WIREPAD1,6/0,8; 1,6/0,8
RX: SJ
SCL: WIREPAD1,6/0,8; 1,6/0,8
SDA: WIREPAD1,6/0,8; 1,6/0,8
TX: SJ
U1: TS1117-3.3V; SOT223
UART_WIFI: FTDI-3V3; FTDI
VIN: WIREPAD1,6/0,8; 1,6/0,8
WIFI-WLAN: RS9110-N-11-22; RS9110-N-11-21
X1, X2, X3, X4: PASSER

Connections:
0: 0.1, ARD.0 (RX/0), RX.1
1: 1.1, ARD.1 (TX/1), TX.1
3V3: 3.3V.1, 3V3.3, ARD.3V3
3V_OUT: 3V3.1, C3.1, C4.+, U1.2 (VO)
5V: 5V.1, ARD.5V, C1.+, C2.1, U1.3 (VI)
+3V3: 3V3.2, C5.1, C7.1, C8.1, C9.1, IC1.20 (VCC), R2.2, R3.1, R8.2, WIFI-WLAN.46 (3V3), WIFI-WLAN.47 (3V3)
A0: AIN0.1, ARD.AIN0
A1: AIN1.1, ARD.AIN1
AREF: ARD.AREF, AREF.1
GND: AGND.1, ARD.GND@1 (GND), ARD.GND@2 (GND), ARD.GND@3 (GND), C1.-, C2.2, C3.2, C4.-, C5.2, C6.1, C7.2, C8.2, C9.2, GND.1, GND..1, IC1.1 (G), IC1.2 (A1), IC1.4 (A2), IC1.6 (A3), IC1.8 (A4), IC1.10 (GND), IC1.17 (A4), R4.1, R5.1, RESET.2 (S), RESET.3 (S1), U1.1 (GND), UART_WIFI.1 (GND), UART_WIFI.2 (CTS), WIFI-WLAN.10 (GND), WIFI-WLAN.16 (GND), WIFI-WLAN.20 (GND), WIFI-WLAN.21 (GND), WIFI-WLAN.48 (GND), WIFI-WLAN.GND
IOREF: ARD.IOREF, IOREF.1
unnamed: ARD.SCL (AIN5/SCL), SCL.1
unnamed: R5.2, WIFI-WLAN.42 (TCK), WIFI-WLAN.43 (TDI), WIFI-WLAN.44 (TMS)
unnamed: ARD.SDA (AIN4/SDA), SDA.1
unnamed: R4.2, WIFI-WLAN.1 (SPI_DIN), WIFI-WLAN.3 (SPI_INTR), WIFI-WLAN.6 (SDIO_DAT3), WIFI-WLAN.51 (SPI_CLK), WIFI-WLAN.52 (SPI_CS)
unnamed: 4.1, ARD.4
unnamed: 5.1, ARD.5 (PWM/5)
unnamed: 6.1, ARD.6 (PWM/6)
unnamed: 7.1, ARD.7
unnamed: 8.1, ARD.8
unnamed: 9.1, ARD.9 (PWM/9)
unnamed: 10.1, ARD.10 (PWM/SS/10)
unnamed: 11.1, ARD.11 (PWM/MOSI/11)
unnamed: 12.1, ARD.12 (MISO/12)
unnamed: 13.1, ARD.13 (SCK/13)
unnamed: AIN2.1, ARD.AIN2
unnamed: AIN3.1, ARD.AIN3
unnamed: AIN4.1, ARD.AIN4 (AIN4/SDA)
unnamed: AIN5.1, ARD.AIN5 (AIN5/SCL)
unnamed: R6.1, UART_WIFI.5 (RXI)
unnamed: R7.1, UART_WIFI.4 (TXO)
RST: ARD.RST (RESET), RESET.1, RESET.4 (P1), RST..1
VIN: ARD.VIN, VIN.1
WIFI_CS: 3.1, ARD.3 (PWM/3), IC1.19 (G), R8.1
WIFI_RST: R1.2, RST.1
WIFI_RST2: C6.2, R1.1, R2.1, WIFI-WLAN.4 (RESET)
WIFI_RSTI: 2.1, ARD.2, IC1.15 (A3)
WIFI_RSTO: IC1.5 (Y3), RST.2
WIFI_RX: IC1.9 (Y1), R3.2, R7.2, WIFI-WLAN.7 (UART1_IN)
WIFI_RX2: R10.1, TX.2
WIFI_RXI: IC1.11 (A1), R10.2
WIFI_TX: IC1.13 (A2), R6.2, WIFI-WLAN.5 (UART1_OUT)
WIFI_TX2: R9.2, RX.2
WIFI_TXO: IC1.7 (Y2), R9.1

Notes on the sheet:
Released under the Creative Commons Attribution Share-Alike License. http://creativecommons.org/licenses/by-sa/4.0/ Designed by Andreas Watterott (Watterott electronic)

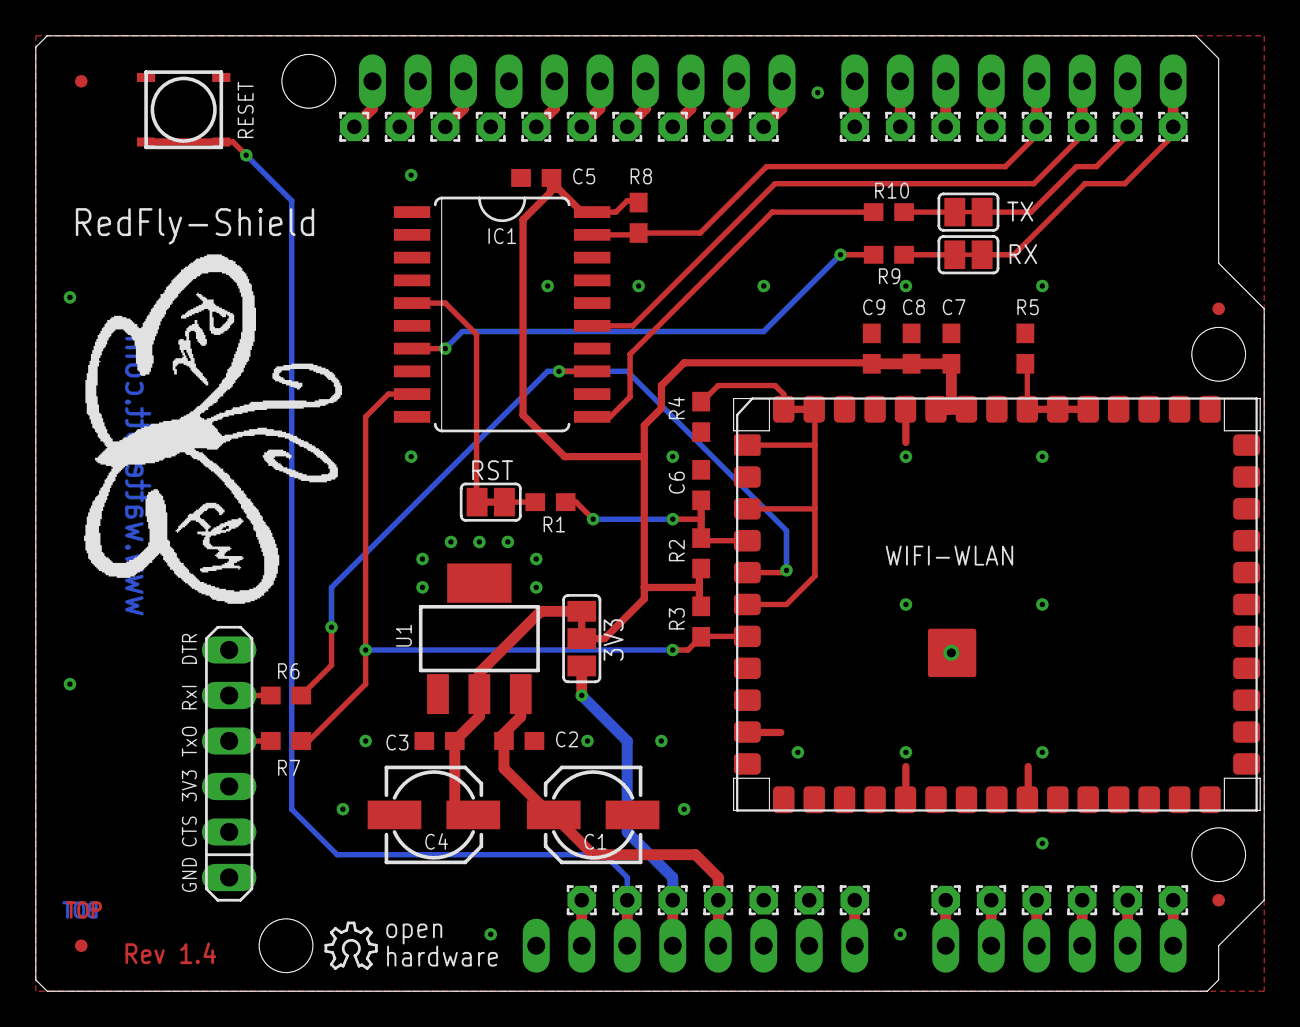
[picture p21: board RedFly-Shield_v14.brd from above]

Board: 2 copper layers, 68.6 x 53.3 mm, 66 parts (1 on the bottom side), 44 nets.
